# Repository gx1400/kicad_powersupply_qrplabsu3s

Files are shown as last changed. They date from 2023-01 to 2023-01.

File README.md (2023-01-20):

# Linear regulator Power supply for QRP Labs Ultimate 3s

Designed in KiCad using NTE1929
PCB fab by OshPark

## Tags
rev1 - First board revision.

## Changelog
2023-01-23: Initial commit, board rev 1 fab'd, assembled, and tested

## To Do
- [ ] clearance between heatsink and fuse clip
- [ ] additional silk screen notes on connectors for connector purpose and polarity
- [ ] change resistors to 0805 SMDs
- [ ] add second NTE1929 for 9V

## Purchased items

### Amazon
- [JST-XH connector kit with crimpers](https://www.amazon.com/gp/product/B07ZHB4BBY)
- [Capacitor kit](https://www.amazon.com/gp/product/B01MSQOX0Q)
- [Resistor kit](https://www.amazon.com/gp/product/B00E3JGGF2)
- [TO220 heatsinks](https://www.amazon.com/gp/product/B078ZXZ1GN)

### Digikey
- [Bourns Inc 3266Y-1-103LF - 10k trimmer pot](https://www.digikey.com/en/products/detail/bourns-inc/3266Y-1-103LF/2535458)
- [SCHURTER Inc. 0752.1242, fuse clips](https://www.digikey.com/en/products/detail/schurter-inc/0752-1242/2644924)
- [Bel Fuse Inc. 5MF 2-R, 2A 5x20mm glass fuse](https://www.digikey.com/en/products/detail/bel-fuse-inc/5MF-2-R/1009036)
- [NTE Electronics, Inc NTE1929, Linear regulator TO-220](https://www.digikey.com/en/products/detail/nte-electronics-inc/NTE1929/11655805)

## License

Shield: [][cc-by-sa]

This work is licensed under a
[Creative Commons Attribution-ShareAlike 4.0 International License][cc-by-sa].

[][cc-by-sa]

[cc-by-sa]: http://creativecommons.org/licenses/by-sa/4.0/
[cc-by-sa-image]: https://licensebuttons.net/l/by-sa/4.0/88x31.png
[cc-by-sa-shield]: https://img.shields.io/badge/License-CC%20BY--SA%204.0-lightgrey.svg

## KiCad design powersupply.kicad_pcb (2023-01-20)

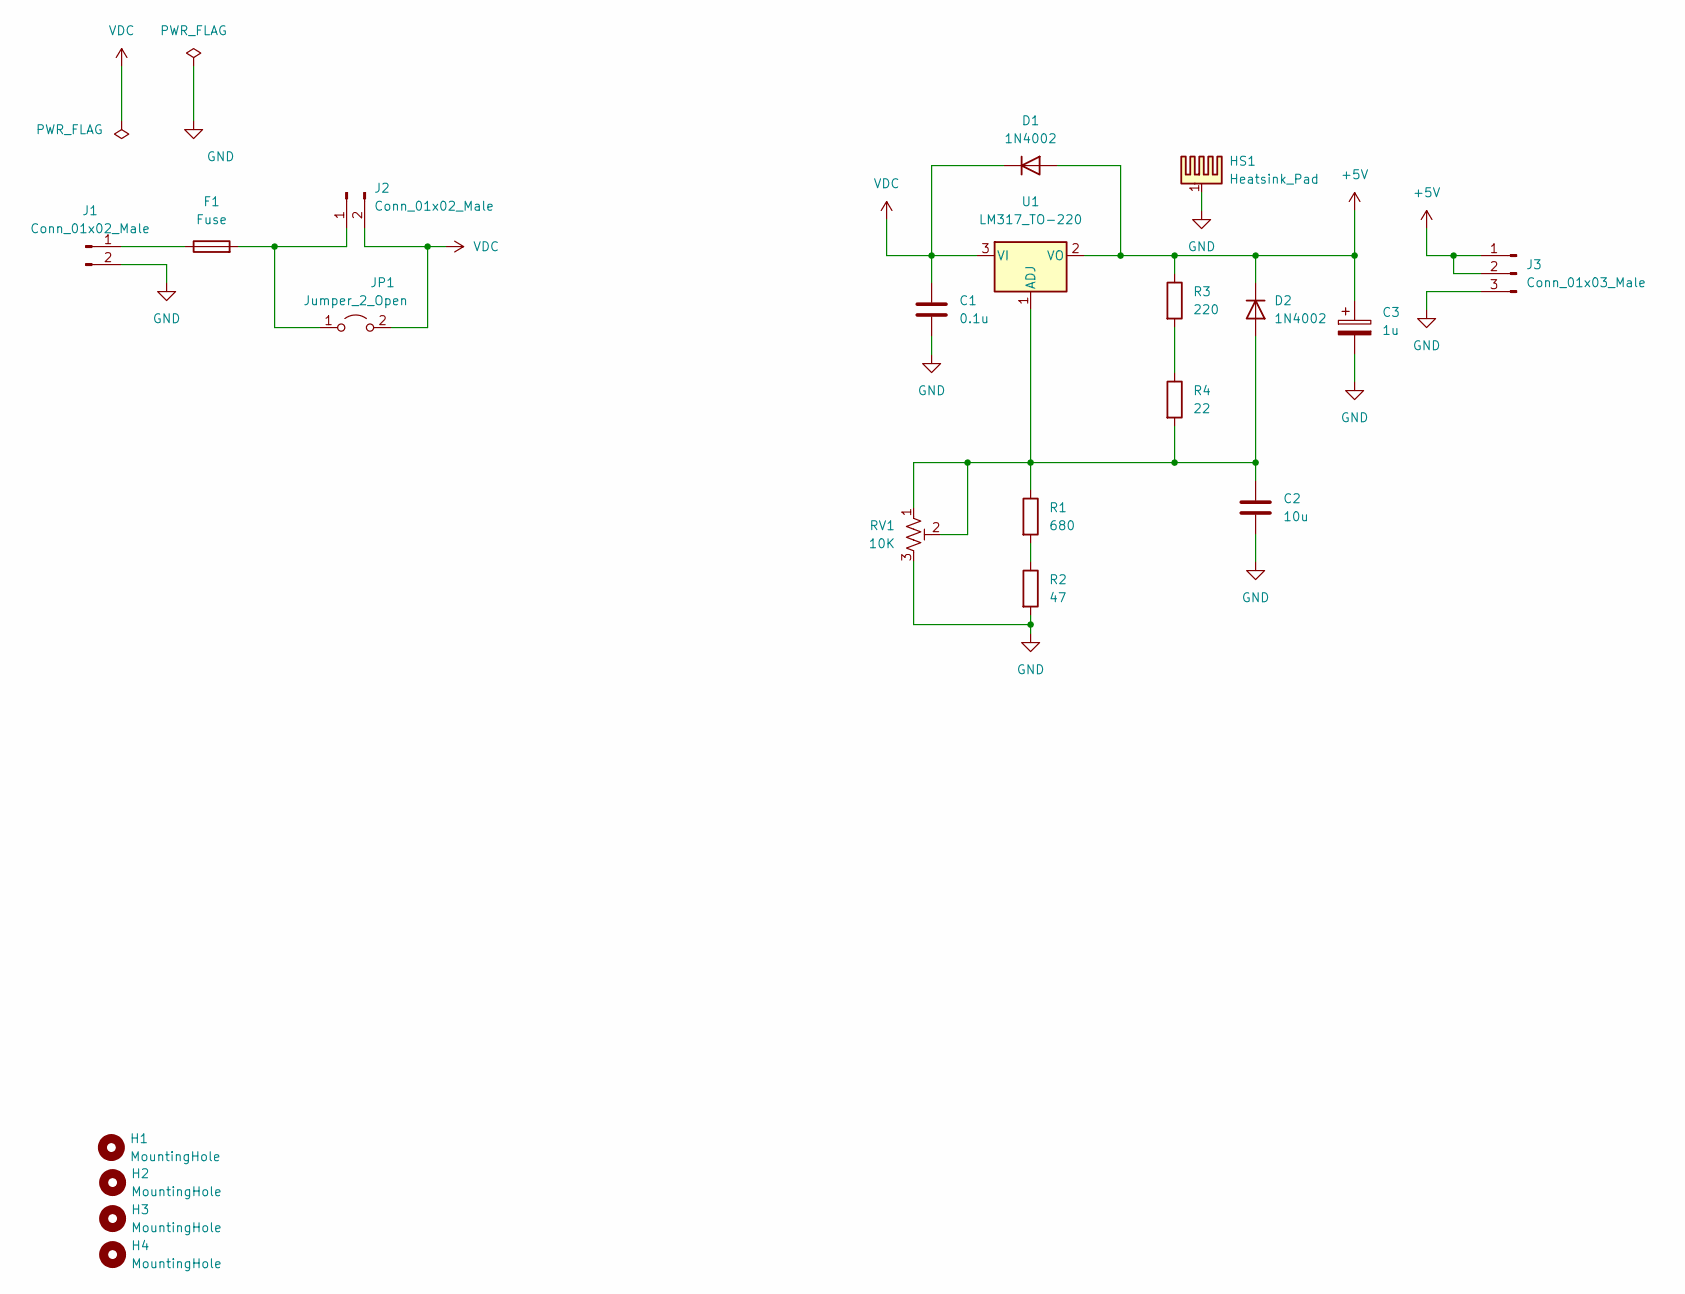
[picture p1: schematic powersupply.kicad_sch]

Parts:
C1: 0.1u; CP_Radial_D4.0mm_P2.00mm
C2: 10u; CP_Radial_D5.0mm_P2.00mm
C3: 1u; CP_Radial_D5.0mm_P2.50mm
D1, D2: 1N4002; D_DO-41_SOD81_P10.16mm_Horizontal
F1: Fuse; Fuseholder_Clip-5x20mm_Schurter_CQM_Inline_P20.60x5.00mm_D1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
H1, H2, H3, H4: MountingHole; MountingHole_3.2mm_M3
HS1: Heatsink_Pad; Heatsink_TO-220-3_Vertical_Amazon_B078ZXZ1GN
J1, J2: Conn_01x02_Male; JST_XH_B2B-XH-AM_1x02_P2.50mm_Vertical
J3: Conn_01x03_Male; JST_XH_B3B-XH-A_1x03_P2.50mm_Vertical
JP1: Jumper_2_Open; TestPoint_2Pads_Pitch2.54mm_Drill0.8mm
R1: 680; R_Axial_DIN0207_L6.3mm_D2.5mm_P10.16mm_Horizontal
R2: 47; R_Axial_DIN0207_L6.3mm_D2.5mm_P10.16mm_Horizontal
R3: 220; R_Axial_DIN0207_L6.3mm_D2.5mm_P10.16mm_Horizontal
R4: 22; R_Axial_DIN0207_L6.3mm_D2.5mm_P10.16mm_Horizontal
RV1: 10K; Potentiometer_Bourns_3266Y_Vertical; PartNumber 3266Y-1-103LF
U1: LM317_TO-220; TO-220-3_Vertical

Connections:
+5V: C3.1, D1.2 (A), D2.1 (K), J3.1, J3.2, R3.1, U1.2 (VO)
GND: C1.2, C2.2, C3.2, HS1.1, J1.2, J3.3, R2.2, RV1.3
unnamed: C2.1, D2.2 (A), R1.1, R4.2, RV1.1, RV1.2, U1.1 (ADJ)
unnamed: F1.1, J1.1
unnamed: F1.2, J2.1, JP1.1 (A)
unnamed: R1.2, R2.1
unnamed: R3.2, R4.1
VDC: C1.1, D1.1 (K), J2.2, JP1.2 (B), U1.3 (VI)

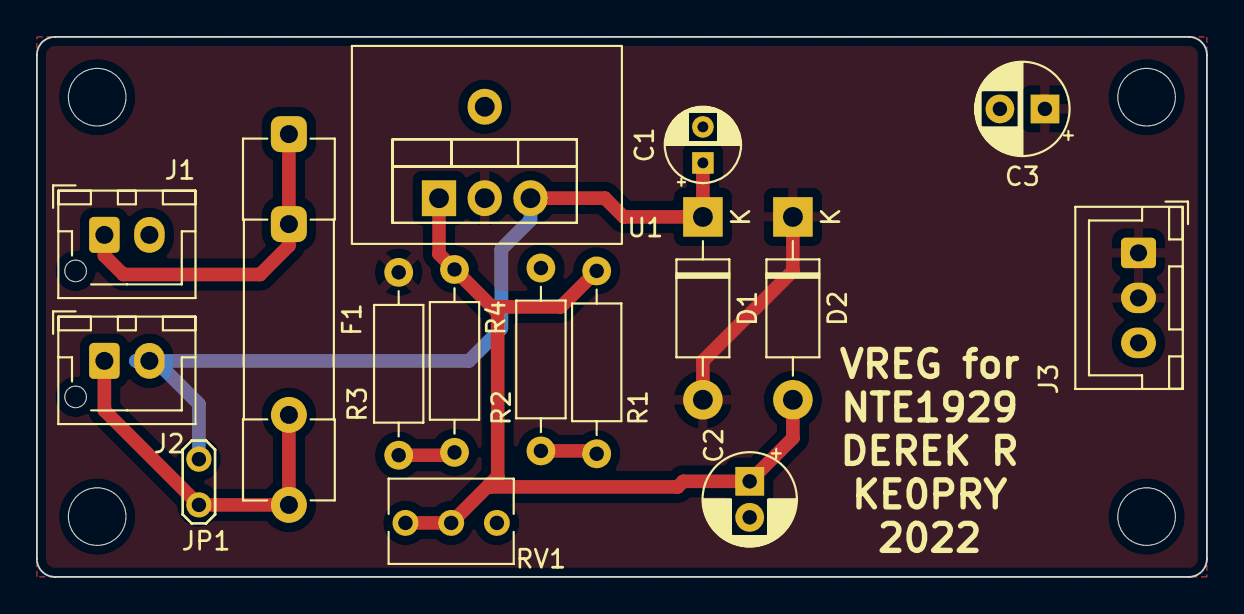
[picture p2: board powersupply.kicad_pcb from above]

Board: 2 copper layers, 65.0 x 30.0 mm, 21 parts (0 on the bottom side), 8 nets.
